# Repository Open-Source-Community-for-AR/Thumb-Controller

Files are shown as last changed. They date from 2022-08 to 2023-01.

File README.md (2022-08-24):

# Tutorial: Thumb-mounted controller

This thumb-mounted controller is an input device for use in extended reality (XR) environments, it operates by sensing its user’s thumb gestures in which thumb contact and movements are processed using various output data. This data is gathered from 2 or more force sensitive resistors and a gyroscope. Recognised gestures are then sent to an XR device via Bluetooth Low Energy (BLE).
In this version, the Thumb-mounted controller uses Adafruit LSM6DS3 libraries for handling the inertial measurement unit (IMU) and read analog data from the board's GPIOs.

## Materials
### Seeed Xiao BLE Sense
This is a BLE development board which comes with a built-in accelerator and gyroscope. The Xiao BLE Sense can be found on the [SEEED website](https://www.seeedstudio.com/Seeed-XIAO-BLE-Sense-nRF52840-p-5253.html).

### Force-Sensitive Resistors (FSRs) 
Two 30g minimum sensitivity resistors are recommended for better gesture recognition. The FSRs can be purchased quite readily but a 0-2kg sensitive FSR on [AliExpress](https://www.aliexpress.com/item/32853977086.html?spm=a2g0o.order_detail.0.0.274ef19cbF8s2J) is a good example.

### Resistors
Two 10,000Ω resistors are required for the controller to function properly. Wattage is not a concern for this device as the board has relatively low power consumption. The resistors can be purchased online fairly easily. However, for beginners, [this guide](https://wiraelectrical.com/10k-ohm-resistor-color-code/) shows the color code for the resistors.

### Li-Po Battery
For this controller, a 3.3V 25mAH battery is soldered on the board. For a more advanced setup, the controller can also be powered by a USB-C port. Without it, however, the battery will last for ~2 hours before it needs to be replaced. So it is up to the user's discretion to decide whether to use the USB-C port or the 25mAH battery.
> Note: The power consumption is not very significant, so some battery banks will only work for a few seconds before the controller loses power.

### 3D Printed Housing
This housing should be printed with [TPU filament](https://www.amazon.com/NinjaTek-3DNF01117505-NinjaFlex-Filament-Midnight/dp/B078JGZRCK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) (link is an example only) for better fitting. The `.stl` file for this housing can be found [here](Housing.stl).

In the future, a better ergornomic version of this housing will be published to improve users' thumbs fitness.

## Controller Architecture
FSRs play an important role on this controller for touch recognition (i.e. swiping and pressing). To use the force sensors, we need to make a voltage divider circuit as shown in the figure below. 

<figure>

Force-Sensitive Resistors connected to a voltage divider

<figcaption align="center"><b>A 3V power contact is connected to one pin on each FSR while the other pin (the analog input and ground) is connected to the resistor.</b></figcaption>

</figure>

## Software Setup
To program the Adafruit Feather Sense board, a few setup steps are needed first.
1. [Set up Arduino on the Seeed board]([https://wiki.seeedstudio.com/XIAO-BLE_CircutPython/](https://wiki.seeedstudio.com/XIAO_BLE/))

## Hardware Details
The housing is comprised of two parts, one for holding the Xiao BLE Sense board and the other for mounting the user’s thumb. Under the thumb mount, the force sensitive pads of the two FSRs are stiched as illustrated in the figure below:

<figure>



<figcaption align="center"><b>The controller can be powered either by connecting to a computer or using an external battery. A battery wristband is designed for mounting the battery to the thumb mount.</b></figcaption>

</figure>

*See the [3D Printed Housing](#3d-printed-housing) section for more details on the housing.*

## Gestures
The thumb controller senses the finger gestures and change its input state in response with the sensed gestures and sends it to the AR headset via BLE. At the moment, this controller supports the following gestures:
- Swiping left/right
- Swiping up/down
- Quick press
- Long press

*More gestures will be added in the future.*

## Contributions
This device was designed and developed by [SoundxVision](https://soundxvision.io) with this [thesis at VAMK](https://www.theseus.fi/handle/10024/744024) by [@phuoctr](https://github.com/phuoctr)  as a basis for the concept.

We would like to thank all of the contributors to this project.

<a href="https://github.com/phuoctr/ThumbControllerHID/graphs/contributors">
  
</a>

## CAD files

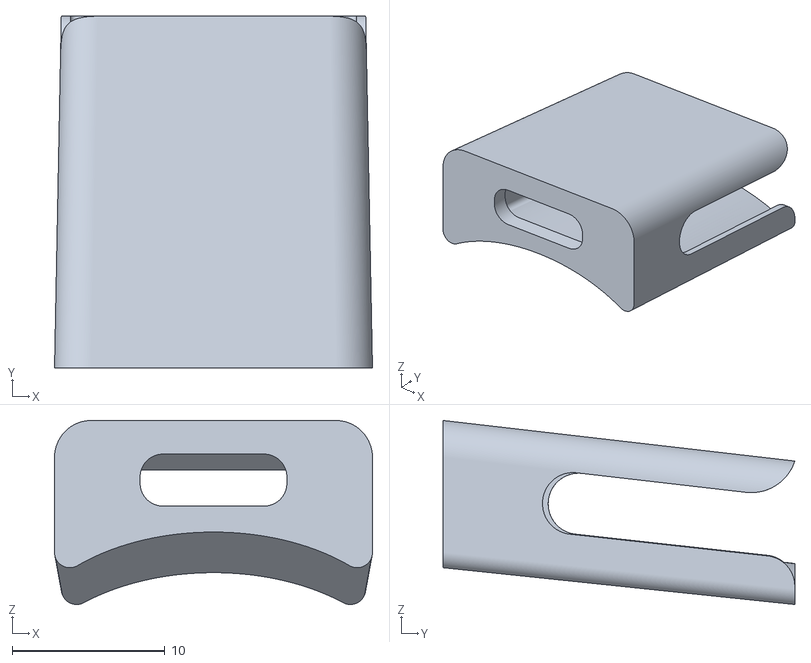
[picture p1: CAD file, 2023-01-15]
Housing/Insert.stl
20.8 x 23.0 x 12.0

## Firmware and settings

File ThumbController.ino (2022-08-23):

#include "ThumbController.h"
#include <LSM6DS3.h>
#include <Wire.h>
#include <ArduinoBLE.h>

//BLE service
BLEService HIDService ("555A0002-0000-467A-9538-01F0652C74E8");
BLECharacteristic HIDCharacteristic ("555A0002-0002-467A-9538-01F0652C74E8", BLERead | BLENotify, 3 , true);


//Create an instance of class LSM6DS3
LSM6DS3 lsm6ds3(I2C_MODE, 0x6A);    //I2C device address 0x6A


uint8_t state = IDLING;
uint8_t previousState = IDLING;
int timer0 = TOUCH_RELEASE_DURATION; // timer for touch releasing
int timer1 = SWIPING_UPDATE_INTERVAL; // time slot for angle calc
int timer2 = MINIMUM_PRESS_DOWN_DURATION; // timer for press sensing

// timer references
uint32_t timerRef0; // timestamp for touch releasing
uint32_t timerRef1; // timestamp for angle calc
uint32_t timerRef2; // timestamp for pressing

// touch release
bool firstPointRelease = false;
bool secondPointRelease = false;
bool firstZoneLeft = false;
bool firstZoneRight = false;
bool secondZoneLeft = false;
bool secondZoneRight = false;

//z Axis rotation
float zAxisRotation;

int FSR0,FSR1;

void setup() {
  Serial.begin(9600);
  lsm6ds3.begin();
  //lsm6ds3.settings.gyroEnabled = 0;
  setupBLE();
}

void loop() {
  BLE.poll();
  // Check connection status
  BLEDevice XRDevice = BLE.central();
  if(XRDevice.connected()){
    byte data[3]; // {1st byte: input state, 2nd-3rd bytes: press strength}
    updateState(data);  
    if(HIDCharacteristic.subscribed())
      {
        HIDCharacteristic.writeValue(data, 3, false);
      }
  }
  //Serial.println(lsm6ds3.readFloatGyroZ());
}

void setupBLE(void){
  const char deviceName[13] = "XRController";

  // begin initialization
  if (!BLE.begin()) 
    {
      Serial.println("Unable to start BLE!");
  
      while (1);
    }

    // set adv name
    BLE.setLocalName("XRController");

    // include service uuid in adv paket
    BLE.setAdvertisedService(HIDService);

    // add characteristic to HID service
    HIDService.addCharacteristic(HIDCharacteristic);

    // add HID service
    BLE.addService(HIDService);

    // initialize the characteristic value
    HIDCharacteristic.writeValue(state);

    // start advertising
    BLE.setAdvertisingInterval(320);
    BLE.advertise();
    
    // set connInt
    BLE.setConnectionInterval(0x0006, 0x0c80); // 7.5 ms minimum, 4 s maximum

    // set handlers
    BLE.setEventHandler(BLEConnected, blePeripheralConnectHandler);
    BLE.setEventHandler(BLEDisconnected, blePeripheralDisconnectHandler);
  }

void blePeripheralConnectHandler(BLEDevice device) {
  lsm6ds3.settings.gyroEnabled = 1;
}
void blePeripheralDisconnectHandler(BLEDevice device) {
  lsm6ds3.settings.gyroEnabled = 0;
}

void updateState(byte* data){
 // read the input on analog pin 0:
 FSR0 = analogRead(A0); // first force sensor
 FSR1 = analogRead(A2); // second force sensor
  
  switch (state) {

    case IDLING: // Default state, listen for change on first and second force sensors
      
      if (FSR0 >= NORMAL_TOUCH || FSR1 >= NORMAL_TOUCH) state = TOUCHING;
      break;

    case TOUCHING: // When contact is detected on at least one force sensor
      
      if (FSR0 >= NORMAL_TOUCH && FSR1 >= NORMAL_TOUCH) break; // Not yet built
      // first point sensing
      if (FSR0 >= NORMAL_TOUCH && FSR0 < HARD_PRESS) { // Light-medium pressure on 1s force sensor
        state = FIRST_ZONE_TOUCHING; // Set state to swiping
        timerRef1 = millis(); // Start time reference for calculating z Axis rotation
      }
      else if (FSR0 >= HARD_PRESS){ 
        state = FIRST_ZONE_START_PRESS; // Hard press on first force sensor
        timerRef2 = millis();
      }
      // second point sensing
      if (FSR1 >= NORMAL_TOUCH && FSR1 < HARD_PRESS) { // Light-medium pressure on 2 force sensor
        state = SECOND_ZONE_TOUCHING; // Set state to swiping
        timerRef1 = millis();
      }
      else if (FSR1 >= HARD_PRESS) {
        state = SECOND_ZONE_START_PRESS; // Hard press on first force sensor
        timerRef2 = millis();
      }
      break;

    case FIRST_ZONE_TOUCHING:   
      if (FSR0 < NORMAL_TOUCH) { 
        state = TOUCH_RELEASE;
        firstPointRelease = true;
        timerRef0 = millis(); // start timer
        if(firstZoneLeft){
            state = FIRST_ZONE_LEFT;
            firstZoneLeft = false;
            break;
          } 
        if(firstZoneRight){
            state = FIRST_ZONE_RIGHT;
            firstZoneRight = false;
            break;
          }
      }
      else if (FSR0 >= HARD_PRESS) { // pressure > 600 => pressing
        state = FIRST_ZONE_START_PRESS;
        timerRef2 = millis(); // timer ref for pressing
      }
      else {
        if (timer1 > 0) {
          // Integration from angular velocity to rotation
          zAxisRotation += lsm6ds3.readFloatGyroZ() * (millis() - timerRef1) / 1000;
          timer1 -= millis() - timerRef1;
          timerRef1 = millis();
          if (zAxisRotation >= SWIPING_ANGLE) {
            firstZoneLeft = true;
            zAxisRotation = 0;
          }
          else if (zAxisRotation <= -SWIPING_ANGLE) {
            firstZoneRight = true;
            zAxisRotation = 0;
          }
        }
        else {
          timer1 = SWIPING_UPDATE_INTERVAL;
          zAxisRotation = 0;
          firstZoneLeft = false;
          firstZoneRight = false;
        }
      }
      break;

    case FIRST_ZONE_LEFT:
      state = IDLING;
      break;

    case FIRST_ZONE_RIGHT:
      state = IDLING;
      break;

    case FIRST_ZONE_START_PRESS:
      // If pressure down to 10 and below, just switch to touch release
      if (FSR0 <= NONE_CONTACT){ 
        state = IDLING;
        break;
      }
      // The timer count down from 500
      if (timer2 > 0) {
        timer2 -= millis() - timerRef2; //On first time, the timerRef2 was initialized on TOUCHING
        timerRef2 = millis(); //Re-initialized for next loop
        if (FSR0 < HARD_PRESS) state = FIRST_ZONE_QUICK_PRESS; //if pressing shorter than 500ms => press once
      }
      else { 
          timer2 = 0;
          state = FIRST_ZONE_PRESS_DOWN;
      }
      break;

    case FIRST_ZONE_QUICK_PRESS:
      // Do something with single tap
      timer2 = MINIMUM_PRESS_DOWN_DURATION; // reset timer 2
      state = TOUCHING;
      break;

    case FIRST_ZONE_PRESS_DOWN:
      // keep state until force below 600
      if(FSR0 < HARD_PRESS) {
        state = TOUCHING;
        timer2 = MINIMUM_PRESS_DOWN_DURATION; // reset timer 2
        }
      break;

    case SECOND_ZONE_TOUCHING:
      
      if (FSR1 <= NONE_CONTACT) {
        state = TOUCH_RELEASE;
        secondPointRelease = true;
        timerRef0 = millis();
      }
      else if (FSR1 >= HARD_PRESS) {
        state = SECOND_ZONE_START_PRESS;
        timerRef2 = millis();
      }
      else {
        if (timer1 > 0) {
           zAxisRotation += lsm6ds3.readFloatGyroZ() * (millis() - timerRef1) / 1000;
          timer1 -= millis() - timerRef1;
          timerRef1 = millis();
          if (zAxisRotation >= SWIPING_ANGLE) {
            secondZoneLeft = true;
            //state = SECOND_ZONE_LEFT;
            zAxisRotation = 0;
          }
          else if (zAxisRotation <= -SWIPING_ANGLE) {
            secondZoneRight = true;
            //state = SECOND_ZONE_RIGHT;
            zAxisRotation = 0;
          }
        }
        else {
          timer1 = SWIPING_UPDATE_INTERVAL;
          zAxisRotation = 0;
        }
      }
      break;

    case SECOND_ZONE_LEFT:
      //Do sth
      state = TOUCHING;
      break;

    case SECOND_ZONE_RIGHT:
      //Do sth
      state = TOUCHING;
      break;

    case SECOND_ZONE_START_PRESS:
//      // If pressure down to 10 and below, just switch to switch release
      if (FSR1 <= NONE_CONTACT){ 
        state = IDLING;
        break;
      }
//      // The timer count down for the duration of defined minimum press down duration
      if (timer2 > 0) {
        timer2 -= millis() - timerRef2; //On first time, the timerRef2 was initialized on TOUCHING
        timerRef2 = millis(); //Re-initialized for next loop
        if (FSR1 < HARD_PRESS) state = SECOND_ZONE_QUICK_PRESS; //if pressing shorter than 100ms => press once
      }
      else { 
        timer2 = 0;
        state = SECOND_ZONE_PRESS_DOWN;
      }
      break;

    case SECOND_ZONE_QUICK_PRESS:
      // Do something with single tap
      timer2 = MINIMUM_PRESS_DOWN_DURATION; // reset timer 2
      state = TOUCHING;
      break;

    case SECOND_ZONE_PRESS_DOWN:
      // keep state until force below 600
      if(FSR1 < HARD_PRESS) {
        state = TOUCHING;
        timer2 = MINIMUM_PRESS_DOWN_DURATION; // reset timer 2
        }
      break;
      
    case TOUCH_RELEASE:
      timer0 -= (millis() - timerRef0);
      timerRef0 = millis();
      if (timer0 <= 0){
          timer0 = TOUCH_RELEASE_DURATION;
          state = IDLING;
          // After touch release interval without any touch, reset first/secondTouchRelease bool
          firstPointRelease = false; 
          secondPointRelease = false;
      }
      else{
        if(secondZoneLeft){
            state = SECOND_ZONE_LEFT;
            secondZoneLeft = false;
            timer0 = TOUCH_RELEASE_DURATION;
            break;
          } 
        else if(secondZoneRight){
            state = SECOND_ZONE_RIGHT;
            secondZoneRight = false;
            timer0 = TOUCH_RELEASE_DURATION;
            break;
          }
         
         
        if(firstPointRelease && FSR1 > NONE_CONTACT){
          firstPointRelease = false;
          timer0 = TOUCH_RELEASE_DURATION;
          state = UP;
          break;
          }
          
        if(secondPointRelease && FSR0 >= NONE_CONTACT){
          secondPointRelease = false;
          timer0 = TOUCH_RELEASE_DURATION;
          state = DOWN;
          break;
          }       
      }
      break;

    case UP:
        state = IDLING;
        break;

    case DOWN:
        state = IDLING;
        break;
  }

  previousState = state;

  int pressure = (FSR0>FSR1)?FSR0:FSR1;
  data[0] = state;
  data[1] = pressure & 0xff;
  data[2] = (pressure >> 8) & 0xff; 
}
